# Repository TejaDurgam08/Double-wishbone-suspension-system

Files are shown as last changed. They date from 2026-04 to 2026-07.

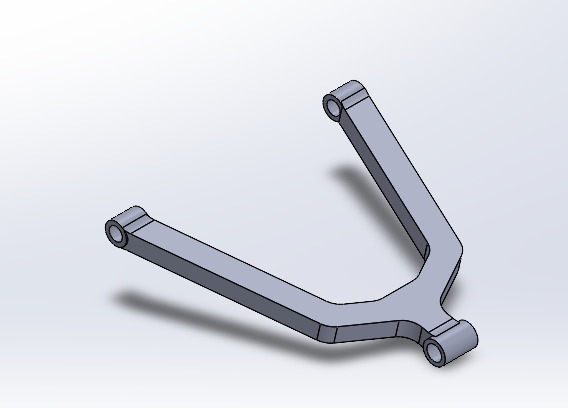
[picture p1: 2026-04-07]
images/IMG-20251128-WA0012.jpg

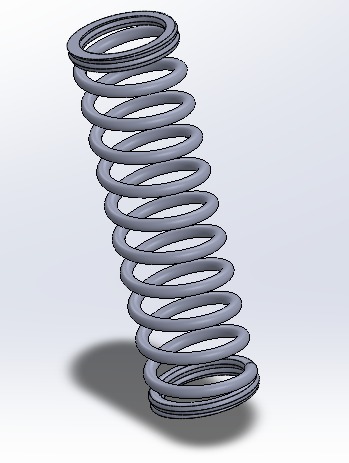
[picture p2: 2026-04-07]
images/IMG-20251128-WA0010.jpg

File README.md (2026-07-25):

# Double-wishbone-suspension-system

IMG-20251128-WA0008
IMG-20251128-WA0011

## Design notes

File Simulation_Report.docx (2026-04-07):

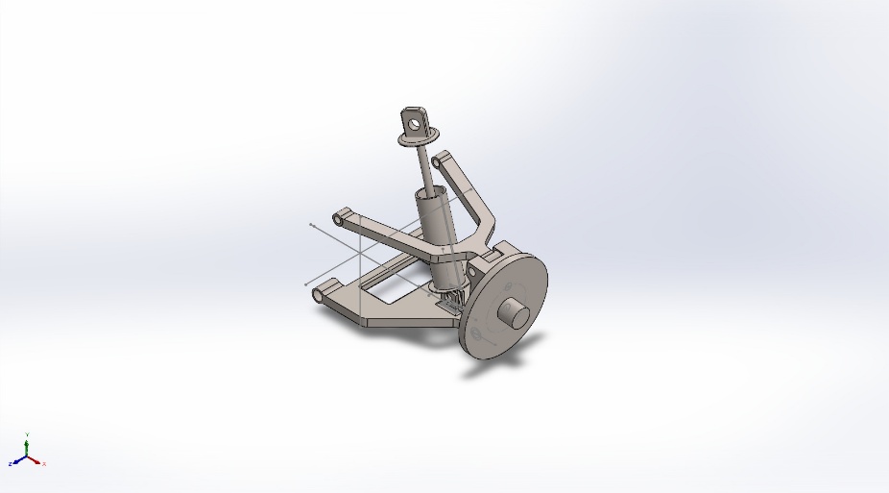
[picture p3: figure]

Simulation of tests_2 - Copy

Date: 28 November 2025
Designer: Solidworks

Study name: Test_1_static

Analysis type: Static
Description No Data

# Assumptions

# Model Information

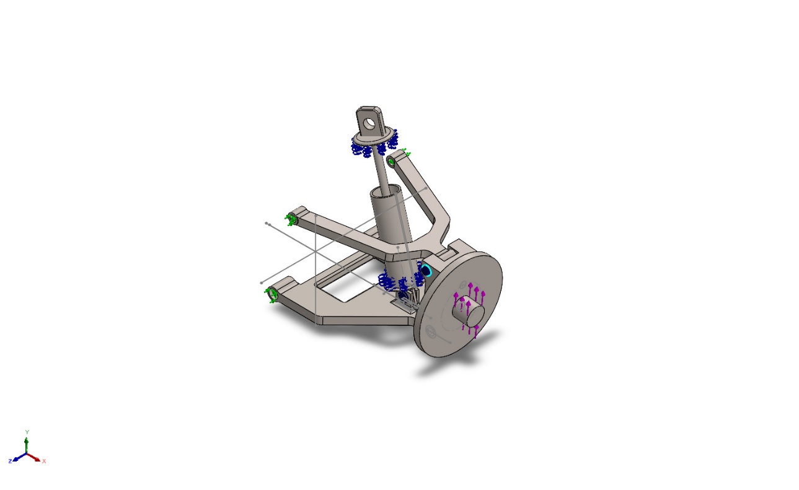
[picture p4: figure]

Model name: tests_2 - Copy

Current Configuration: Default

Solid Bodies
Document Name and Reference | Treated As | Volumetric Properties | Document Path/Date Modified
Boss-Extrude7[1] | Solid Body | Mass:0.00462 kg Volume:6e-07 m^3 Density:7,700 kg/m^3 Weight:0.045276 N | D:\Dome_assignment\DoME project\my\version_1\base_2.SLDPRT Nov 17 12:33:01 2025

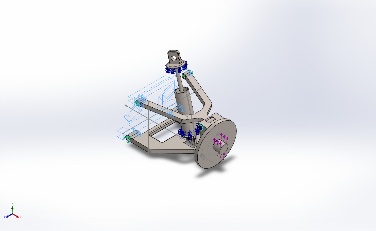
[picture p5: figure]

Cut-Extrude2 | Solid Body | Mass:0.741422 kg Volume:9.62885e-05 m^3 Density:7,700 kg/m^3 Weight:7.26593 N | D:\Dome_assignment\DoME project\my\version_1\base_2.SLDPRT Nov 17 12:33:01 2025

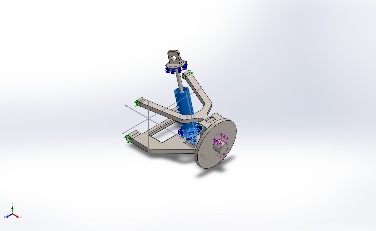
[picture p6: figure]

Revolve2 | Solid Body | Mass:0.161137 kg Volume:2.09269e-05 m^3 Density:7,700 kg/m^3 Weight:1.57914 N | D:\Dome_assignment\DoME project\my\version_1\damper_pipe.SLDPRT Nov 27 22:18:26 2025

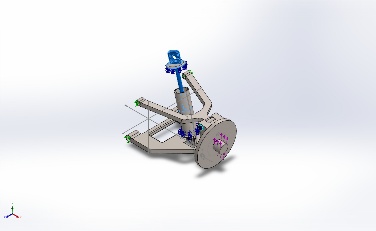
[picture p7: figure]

Cut-Extrude1 | Solid Body | Mass:0.0996239 kg Volume:1.29382e-05 m^3 Density:7,700 kg/m^3 Weight:0.976314 N | D:\Dome_assignment\DoME project\my\version_1\damper_rod.SLDPRT Nov 28 00:48:46 2025

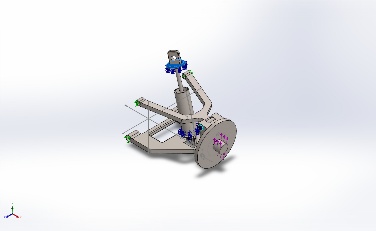
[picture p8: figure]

Fillet1 | Solid Body | Mass:0.0174824 kg Volume:2.27044e-06 m^3 Density:7,700 kg/m^3 Weight:0.171327 N | D:\Dome_assignment\DoME project\my\version_1\damper_rod.SLDPRT Nov 28 00:48:46 2025

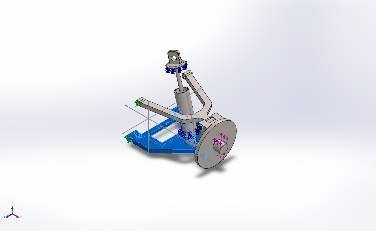
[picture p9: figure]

Fillet16 | Solid Body | Mass:0.854805 kg Volume:0.000111014 m^3 Density:7,700 kg/m^3 Weight:8.37709 N | D:\Dome_assignment\DoME project\my\version_1\lower_2 - Copy.SLDPRT Nov 17 13:17:45 2025

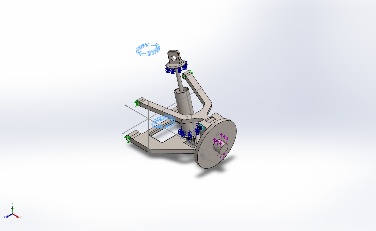
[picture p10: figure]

Cut-Extrude1 | Solid Body | Mass:0.312714 kg Volume:4.06231e-05 m^3 Density:7,697.92 kg/m^3 Weight:3.06459 N | D:\Dome_assignment\DoME project\my\version_1\spring - Copy (2).SLDPRT Nov 28 02:52:23 2025

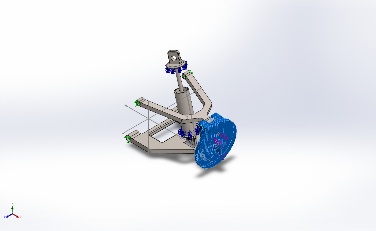
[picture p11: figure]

Boss-Extrude4 | Solid Body | Mass:1.26652 kg Volume:0.000164483 m^3 Density:7,700 kg/m^3 Weight:12.4119 N | D:\Dome_assignment\DoME project\my\version_1\tyre hub - Copy.SLDPRT Nov 27 22:33:03 2025
Fillet4 | Solid Body | Mass:0.331277 kg Volume:4.30229e-05 m^3 Density:7,700 kg/m^3 Weight:3.24651 N | D:\Dome_assignment\DoME project\my\version_1\upper_2 - Copy.SLDPRT Nov 27 21:55:36 2025

# Study Properties

Study name | Test_1_static
Analysis type | Static
Mesh type | Solid Mesh
Thermal Effect: | On
Thermal option | Include temperature loads
Zero strain temperature | 298 Kelvin
Include fluid pressure effects from SOLIDWORKS Flow Simulation | Off
Solver type | Automatic
Inplane Effect: | Off
Soft Spring: | Off
Inertial Relief: | Off
Incompatible bonding options | Automatic
Large displacement | Off
Compute free body forces | On
Friction | Off
Use Adaptive Method: | Off
Result folder | SOLIDWORKS document (D:\Dome_assignment\DoME project\my\version_1)

# Units

Unit system: | SI (MKS)
Length/Displacement | mm
Temperature | Kelvin
Angular velocity | Rad/sec
Pressure/Stress | N/m^2

# Material Properties

Model Reference | Properties | Components

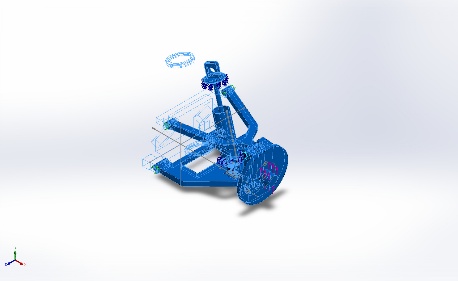
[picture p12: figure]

| Name: Alloy Steel Model type: Linear Elastic Isotropic Default failure criterion: Max von Mises Stress Yield strength: 6.20422e+08 N/m^2 Tensile strength: 7.23826e+08 N/m^2 Elastic modulus: 2.1e+11 N/m^2 Poisson's ratio: 0.28 Mass density: 7,700 kg/m^3 Shear modulus: 7.9e+10 N/m^2 Thermal expansion coefficient: 1.3e-05 /Kelvin | SolidBody 1(Boss-Extrude7[1])(base_2-2), SolidBody 2(Cut-Extrude2)(base_2-2), SolidBody 1(Revolve2)(damper_pipe-1), SolidBody 1(Cut-Extrude1)(damper_rod-1), SolidBody 2(Fillet1)(damper_rod-1), SolidBody 1(Fillet16)(lower_2 - Copy-1), SolidBody 1(Cut-Extrude1)(spring - Copy (2)-1), SolidBody 1(Boss-Extrude4)(tyre hub - Copy-1), SolidBody 1(Fillet4)(upper_2 - Copy-1)

Curve Data:N/A

# Loads and Fixtures

Fixture name | Fixture Image | Fixture Details

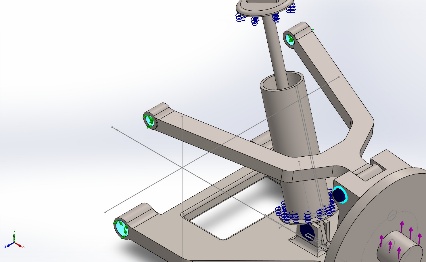
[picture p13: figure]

Fixed Hinge-1 | | Entities: 4 face(s) Type: Fixed Hinge

Resultant Forces

Components | X | Y | Z | Resultant
Reaction force(N) | -60.9249 | -596.9 | 1.20401e-05 | 600.001
Reaction Moment(N.m) | 0 | 0 | 0 | 0

Load name | Load Image | Load Details

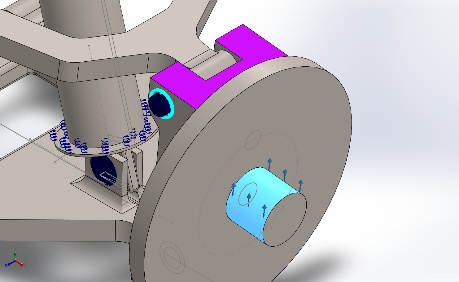
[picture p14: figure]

Force-1 | | Entities: 1 face(s) Reference: Face< 1 > Type: Apply force Values: ---, ---, -,600 N

# Connector Definitions

Connector Name | Connector Details | Connector Image

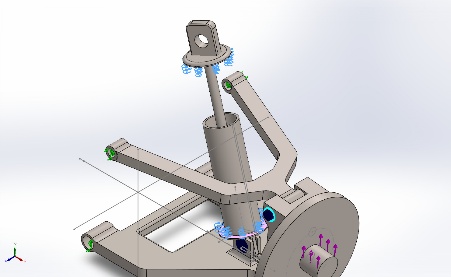
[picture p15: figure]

Spring Connector-1 | Entities: 2 face(s) Type: Spring(Flat parallel faces)(Compression & Extension) Normal stiffness value: 8,108.16 N/m Tangential Stiffness: 0 N/m | Spring Connector-1

Pin/Bolt/Bearing Connector

Model Reference | Connector Details | Strength Details

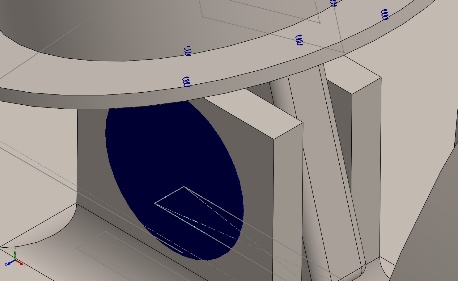
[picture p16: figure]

Pin Connector-1 | Entities: 3 face(s) Type: Pin With retaining ring (No translation): Yes With key (No rotation): No Connection Type: Rigid Units: SI Rotational stiffness value: 0 | No Data

Connector Forces Joint 1

Type | X-Component | Y-Component | Z-Component | Resultant
Axial Force (N) | 0 | 0 | 10.955 | -10.955
Shear Force (N) | 6.9449 | -6.2763 | 0 | 9.3607
Torque (N.m) | 0 | 0 | 1.7213e-11 | -1.7213e-11
Bending moment (N.m) | -0.0595 | -0.0048362 | 0 | 0.059696

Connector Forces Joint 2

Type | X-Component | Y-Component | Z-Component | Resultant
Axial Force (N) | 0 | 0 | 10.955 | -10.955
Shear Force (N) | 6.9449 | -6.2763 | 0 | 9.3607
Torque (N.m) | 0 | 0 | 1.7211e-11 | -1.7211e-11
Bending moment (N.m) | 0.085459 | 0.033561 | 0 | 0.091813

Connector Forces Joint 3

Type | X-Component | Y-Component | Z-Component | Resultant
Axial Force (N) | -0 | -0 | -10.798 | 10.798
Shear Force (N) | 1.4845 | -6.2238 | 0 | 6.3984
Torque (N.m) | 0 | 0 | 1.7213e-11 | -1.7213e-11
Bending moment (N.m) | 0.059799 | 0.017382 | 0 | 0.062274

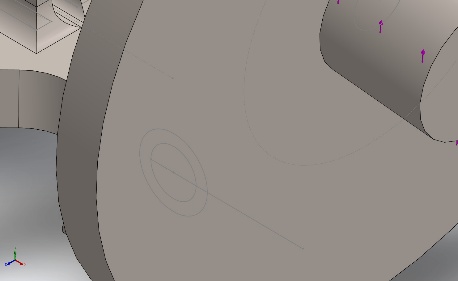
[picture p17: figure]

Pin Connector-4 | Entities: 3 face(s) Type: Pin With retaining ring (No translation): Yes With key (No rotation): No Connection Type: Rigid Units: SI Rotational stiffness value: 0 | No Data

Connector Forces Joint 1

Type | X-Component | Y-Component | Z-Component | Resultant
Axial Force (N) | 0 | 0 | -0.51797 | -0.51797
Shear Force (N) | 569.04 | 1,198.2 | 0 | 1,326.4
Torque (N.m) | 0 | 0 | -1.9454e-12 | -1.9454e-12
Bending moment (N.m) | 6.7217 | -1.5449 | 0 | 6.8969

Connector Forces Joint 2

Type | X-Component | Y-Component | Z-Component | Resultant
Axial Force (N) | 0 | 0 | -0.51797 | -0.51797
Shear Force (N) | 569.04 | 1,198.2 | 0 | 1,326.4
Torque (N.m) | 0 | 0 | -1.5469e-12 | -1.5469e-12
Bending moment (N.m) | 14.252 | -8.4158 | 0 | 16.551

Connector Forces Joint 3

Type | X-Component | Y-Component | Z-Component | Resultant
Axial Force (N) | -0 | -0 | 17.493 | 17.493
Shear Force (N) | 410.21 | 1,098.3 | 0 | 1,172.4
Torque (N.m) | 0 | 0 | -1.944e-12 | -1.944e-12
Bending moment (N.m) | -6.1258 | 0.40365 | 0 | 6.1391

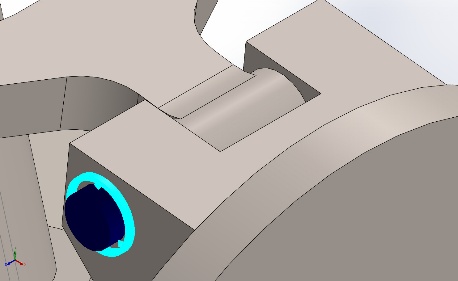
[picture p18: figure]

Pin Connector-5 | Entities: 3 face(s) Type: Pin With retaining ring (No translation): Yes With key (No rotation): No Connection Type: Rigid Units: SI Rotational stiffness value: 0 | No Data

Connector Forces Joint 1

Type | X-Component | Y-Component | Z-Component | Resultant
Axial Force (N) | -0 | -0 | 37.484 | 37.484
Shear Force (N) | -262.15 | 90.807 | 0 | 277.43
Torque (N.m) | 0 | 0 | -2.5977e-12 | -2.5977e-12
Bending moment (N.m) | -0.83893 | -0.29251 | 0 | 0.88846

Connector Forces Joint 2

Type | X-Component | Y-Component | Z-Component | Resultant
Axial Force (N) | -0 | -0 | 65.881 | 65.881
Shear Force (N) | 354.56 | 22.88 | 0 | 355.3
Torque (N.m) | 0 | 0 | -2.4312e-12 | -2.4312e-12
Bending moment (N.m) | -2.176 | -5.6127 | 0 | 6.0197

Connector Forces Joint 3

Type | X-Component | Y-Component | Z-Component | Resultant
Axial Force (N) | 0 | 0 | -65.881 | -65.881
Shear Force (N) | -354.56 | -22.88 | 0 | 355.3
Torque (N.m) | 0 | 0 | -2.5868e-12 | -2.5868e-12
Bending moment (N.m) | 2.5751 | -0.57265 | 0 | 2.638

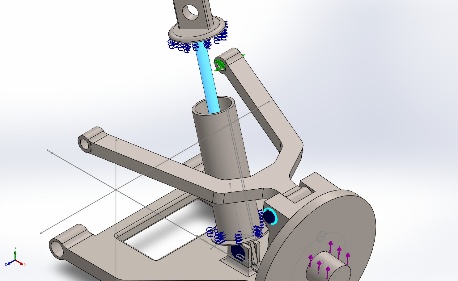
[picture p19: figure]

Pin Connector-6 | Entities: 2 face(s) Type: Pin With retaining ring (No translation): Yes With key (No rotation): No Connection Type: Distributed Units: SI Rotational stiffness value: 0 | No Data

Connector Forces Joint 1

Type | X-Component | Y-Component | Z-Component | Resultant
Axial Force (N) | 0.0016637 | -0.0059329 | -0 | 0.0061618
Shear Force (N) | 0.00068609 | 0.00019239 | -6.5077e-05 | 0.00071552
Torque (N.m) | 2.6322e-14 | -9.3867e-14 | -0 | 9.7488e-14
Bending moment (N.m) | -4.2029e-06 | -1.1786e-06 | -5.4881e-05 | 5.5055e-05

Connector Forces Joint 2

Type | X-Component | Y-Component | Z-Component | Resultant
Axial Force (N) | -0.0016637 | 0.0059329 | 0 | -0.0061618
Shear Force (N) | -0.00068609 | -0.00019239 | 6.5077e-05 | 0.00071552
Torque (N.m) | -2.1816e-13 | 7.7799e-13 | 0 | -8.08e-13
Bending moment (N.m) | -2.4233e-06 | -6.7954e-07 | -2.0471e-05 | 2.0625e-05

# Interaction Information

Interaction | Interaction Image | Interaction Properties
Global Interaction | | Type: Bonded Components: 1 component(s) Options: Independent mesh

# Mesh information

Mesh type | Solid Mesh
Mesher Used: | Blended curvature-based mesh
Jacobian points for High quality mesh | 16 Points
Maximum element size | 10.215 mm
Minimum element size | 0.51075 mm
Mesh Quality | High
Remesh failed parts independently | Off
Reuse mesh for identical parts in an assembly (Blended curvature-based mesher only) | Off

## Mesh information - Details

Total Nodes | 265399
Total Elements | 159451
Maximum Aspect Ratio | 50.794
% of elements with Aspect Ratio < 3 | 95.5
Percentage of elements with Aspect Ratio > 10 | 0.074
Percentage of distorted elements | 0
Time to complete mesh(hh;mm;ss): | 00:00:38
Computer name: | TEJADURGAM

## Mesh Control Information:

Mesh Control Name | Mesh Control Image | Mesh Control Details

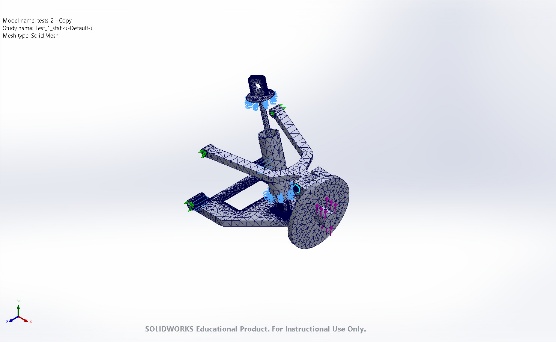
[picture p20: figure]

Control-1 | | Entities: 4 face(s) Units: mm Size: 0.5 Ratio: 0.5
Control-2 | | Entities: 8 face(s) Units: mm Size: 1 Ratio: 1

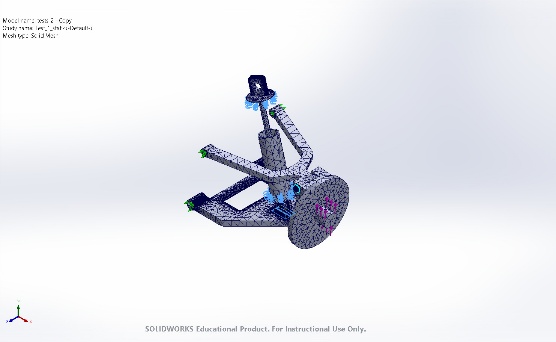
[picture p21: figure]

Control-3 | | Entities: 8 face(s) Units: mm Size: 0.5 Ratio: 0.5

## Mesh Quality Plots

Name | Type | Min | Max
Quality1 | Mesh | - | -

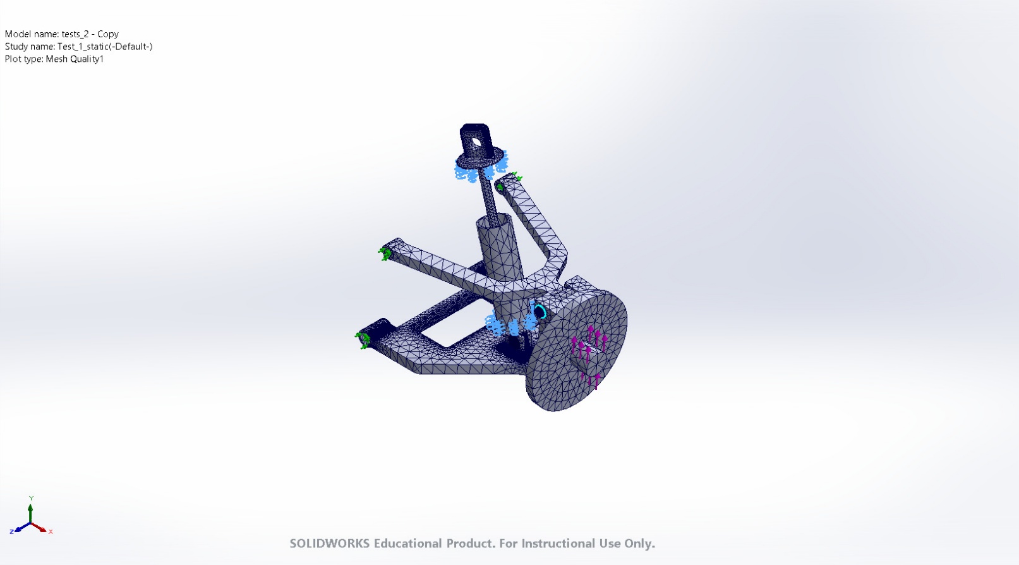
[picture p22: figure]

tests_2 - Copy-Test_1_static-Quality-Quality1

# Sensor Details

No Data

# Resultant Forces

## Reaction forces

Selection set | Units | Sum X | Sum Y | Sum Z | Resultant
Entire Model | N | -60.9249 | -596.9 | 1.20401e-05 | 600.001

## Reaction Moments

Selection set | Units | Sum X | Sum Y | Sum Z | Resultant
Entire Model | N.m | 0 | 0 | 0 | 0

## Free body forces

Selection set | Units | Sum X | Sum Y | Sum Z | Resultant
Entire Model | N | 0.00122065 | 0.00772102 | -0.00320676 | 0.0084491

## Free body moments

Selection set | Units | Sum X | Sum Y | Sum Z | Resultant
Entire Model | N.m | 0 | 0 | 0 | 1e-33

# Beams

No Data

# Study Results

Name | Type | Min | Max
Stress1 | VON: von Mises Stress | 4.769e-01N/m^2 Node: 59681 | 4.849e+08N/m^2 Node: 183649

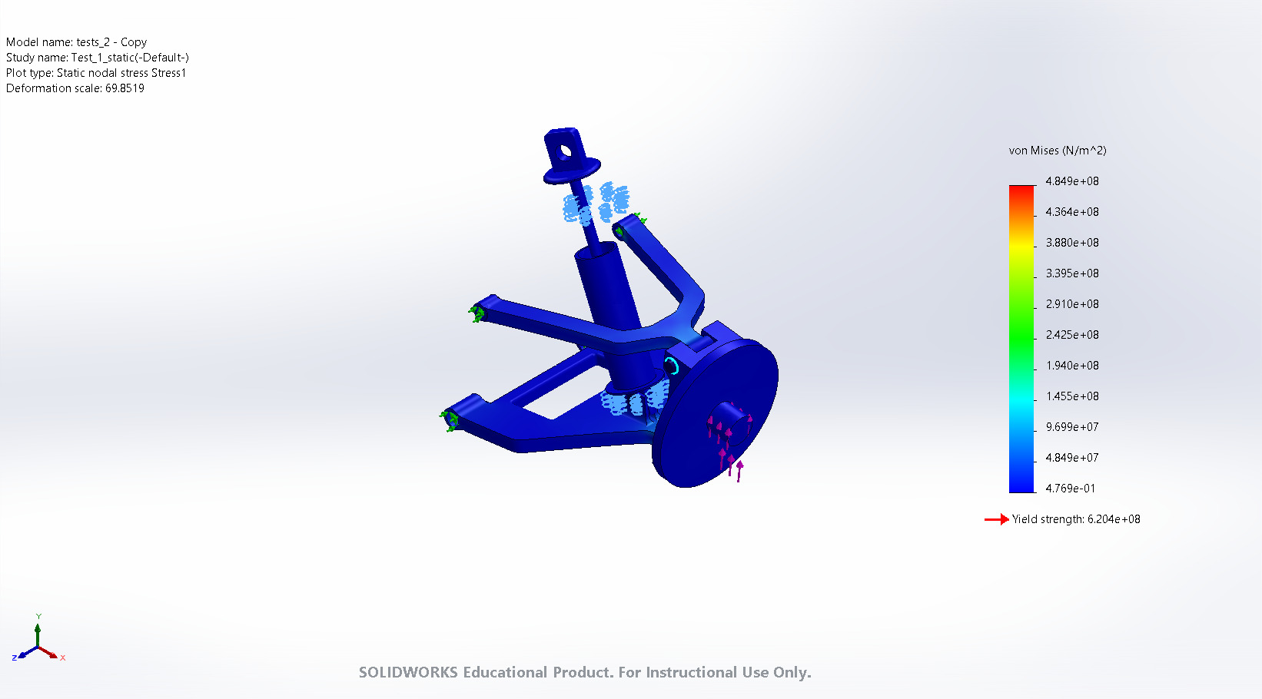
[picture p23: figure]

tests_2 - Copy-Test_1_static-Stress-Stress1

Name | Type | Min | Max
Displacement1 | URES: Resultant Displacement | 4.133e-04mm Node: 663 | 3.852e-01mm Node: 60662

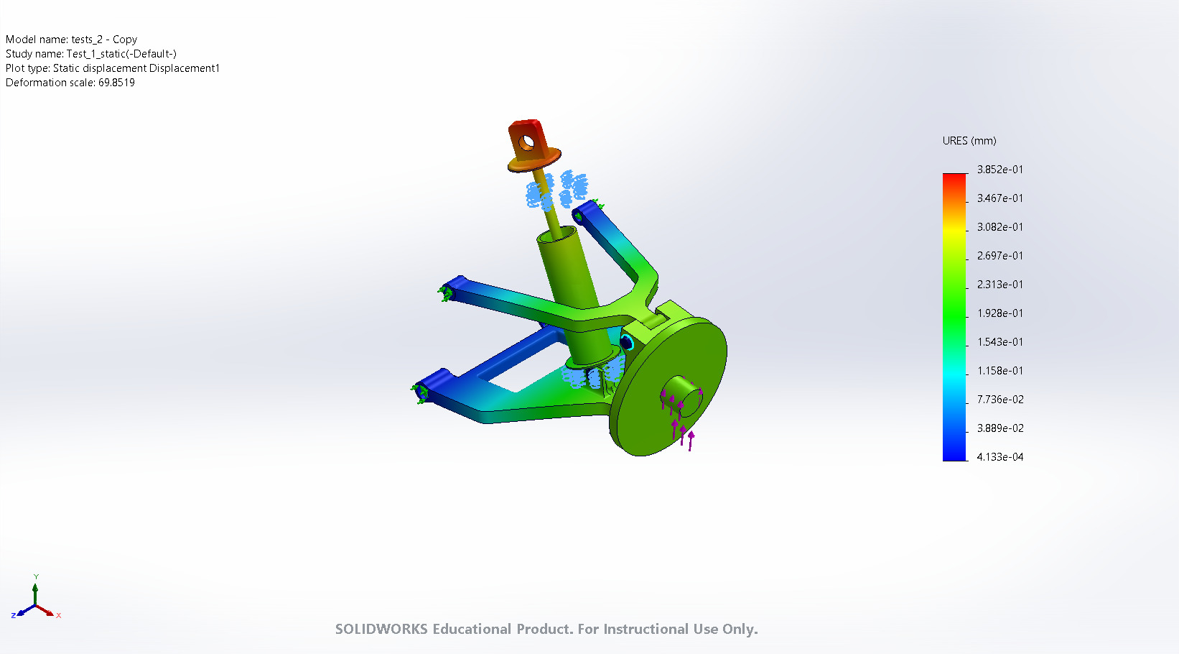
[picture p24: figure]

tests_2 - Copy-Test_1_static-Displacement-Displacement1

Name | Type | Min | Max
Strain1 | ESTRN: Equivalent Strain | 1.762e-12 Element: 146391 | 9.967e-04 Element: 81942

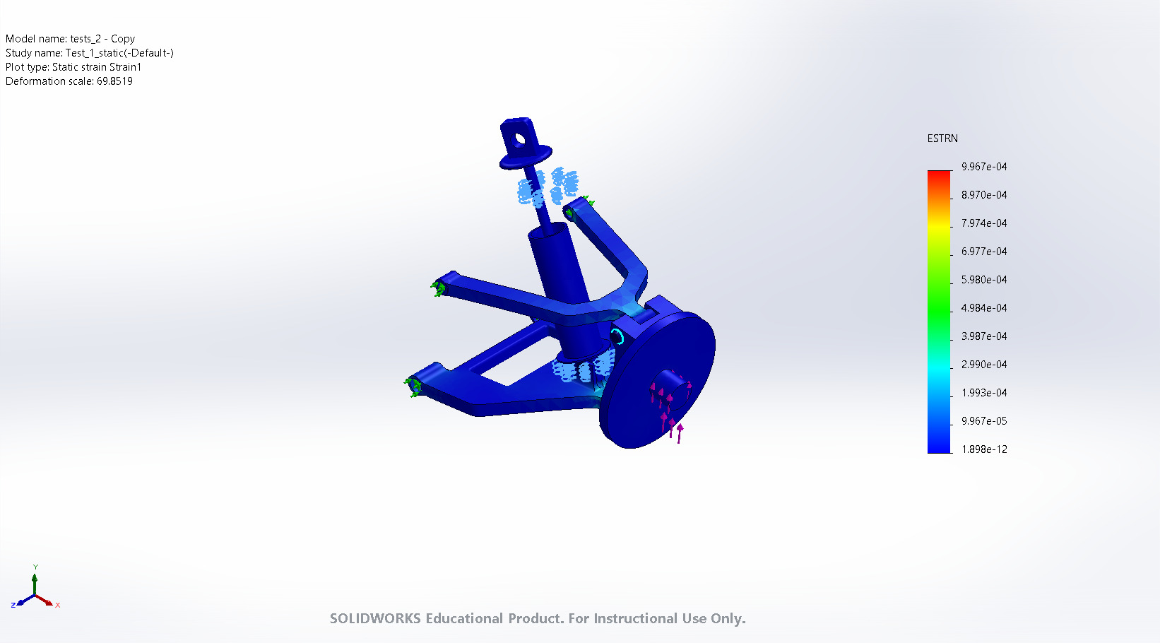
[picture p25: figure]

tests_2 - Copy-Test_1_static-Strain-Strain1

Name | Type | Min | Max
Factor of Safety1 | Automatic | 1.279e+00 Node: 183649 | 1.301e+09 Node: 59681

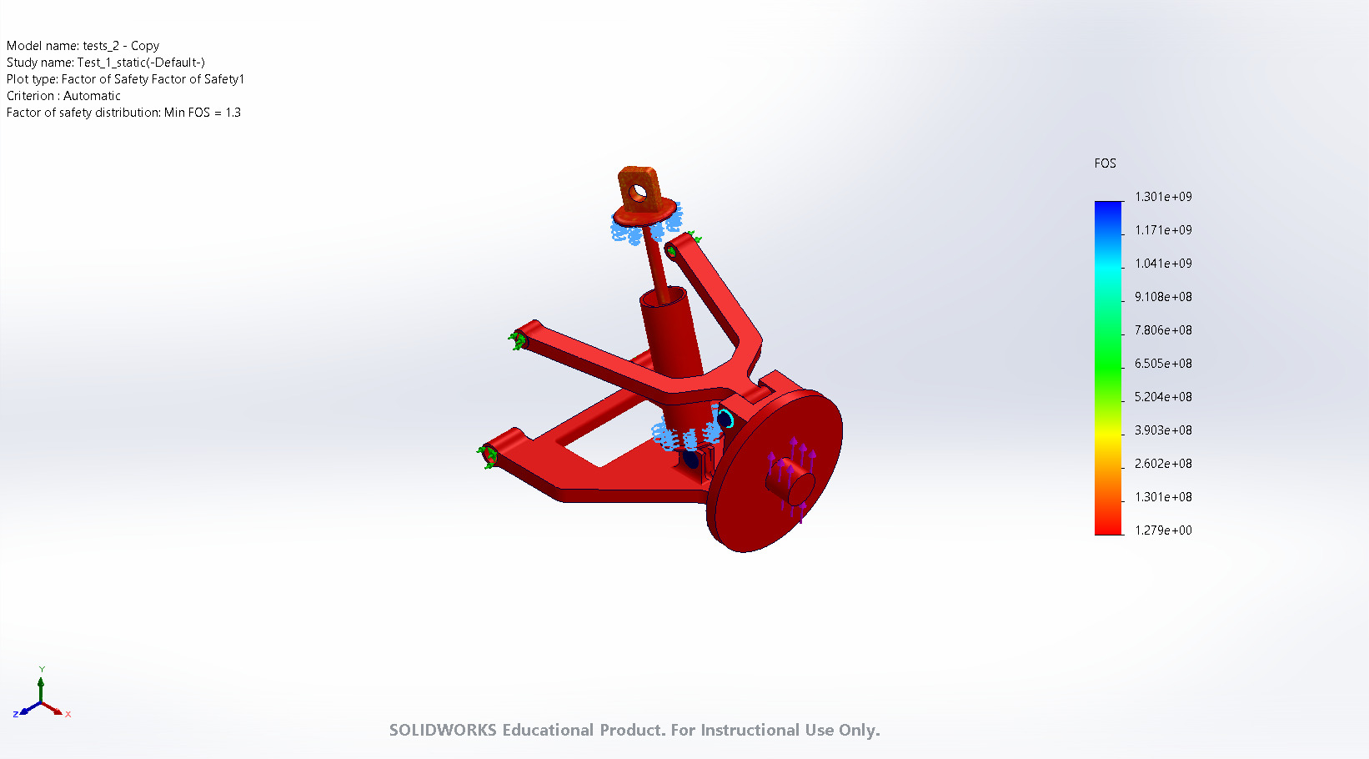
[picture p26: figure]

tests_2 - Copy-Test_1_static-Factor of Safety-Factor of Safety1

# Conclusion

Analyzed with SOLIDWORKS Simulation Simulation of tests_2 - Copy 16

Analyzed with SOLIDWORKS Simulation Simulation of tests_2 - Copy 1

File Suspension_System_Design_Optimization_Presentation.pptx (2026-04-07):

## Design and Optimization of a Four-Wheeler Suspension System

TEAM MEMBERS
- D.TEJA-ME23BT049
- M.PREM SAI -ME23BT037
- N.MAHESH- ME23BT035

## OBJECTIVE

- Analyze and design a four-wheeler suspension consider static and dynamic loads. Perform fatigue and stress analysis using DME data. Propose an optimized design balancing strength and ride comfort.

## Project Overview &Problem Statement

- This project focuses on analyzing and designing a helical coil spring suspension considering real loading conditions.
- Both static (vehicle weight) and dynamic (road-induced shocks) loads are evaluated.
- In this project, a helical coil spring integrated within a double-wishbone system is analyzed and designed.
- Suspension performance must be enhanced without compromising comfort, safety, or manufacturability.
- The project evaluates performance parameters such as stiffness, damping, stress, and fatigue life to improve overall suspension efficiency.

Double_Wishbone_Suspension

## Project Overview &Problem Statement

- The study focuses on a double wishbone suspension system integrated with a helical coil spring and damper, commonly used in passenger vehicles for stability and ride comfort.
- Select materials for spring, damper, and wishbone arms that can safely carry vehicle loads while minimizing weight and cost.
- Develop a CAD model and assembly that captures real-world constraints: suspension travel, clearances, and manufacturability.
- Analyze and optimize the spring–damper–wishbone system to ensure structural integrity, ride comfort, and handling performance.

## DESIGN CONSIDERATIONS

1. Structural Integrity
- Use high-strength, fatigue-resistant materials for spring, damper, and wishbone.
- Design joints and contacts to avoid stress concentrations.
- Ensure adequate safety factors for static and fatigue loads
2. Ride Comfort:
- Tune spring stiffness to absorb bumps.
- Set damper coefficient to control oscillations without harshness.
3. Minimum Ride Height
- Ensure the suspension allows proper ground clearance and ergonomically safe vehicle entry/exit without bottoming out.

## DESIGN CONSIDERATIONS

4. Damper Ergonomics
- Damper and spring response should provide smooth motion with minimal driver input force for comfort and control.
5. Wishbone Geometry
- Dimensions of wishbone arms to achieve correct wheel travel and kinematics while keeping the system compact.
6. Link Geometry & Joint Placement
- Proper geometry and pivot placement ensure smooth motion, uniform load distribution, and stable suspension operation.
7. Base & Wheel Stability
- Suspension geometry and spring–damper tuning should maintain vehicle stability, center of gravity, and handling performance during turns, bumps, and braking.

## MODELING AND ASSEMBLY

- Here are the CAD-modeled components that form the complete four-wheeler suspension assembly, including the helical coil spring, hydraulic damper, and double-wishbone arms.
- These visuals help in understanding the geometry, mounting points, kinematics, and overall interaction between the spring–damper unit and the wishbone linkage.
- They also illustrate how the spring and damper compress and extend during wheel movement,the upper and lower wishbones control wheel alignment and motion path

main

## MODELING AND ASSEMBLY

Damper (Mono-Tube):
Material Selection:
- High-strength steel or aluminum alloys
- Polymer or rubber sealing materials
Function:
- Controls spring oscillations
- Improves ride stability and handling
- Reduces Vibrations & Impacts


## MODELING AND ASSEMBLY

Helical Spring:
Material Selection:
- Chrome–Silicon (Cr–Si) Steel
High strength, excellent fatigue resistance, ideal for heavy-load and high-stress suspension springs.
- Chrome–Vanadium (Cr–V) Steel
Good toughness, high endurance limit, better performance under repeated dynamic loads.
- Spring Steel (High-Carbon Steel)
Cost-effective, reliable option with good elasticity and durability for standard suspension systems.
Function:
- Supports Vehicle Weight
- Absorbs Road Shocks
- Maintains Suspension Geometry

spring

## MODELING AND ASSEMBLY

Double Wishbone :
Material selection:
- High-strength steel (mild steel or alloy steel)
- Aluminum alloy (e.g., 6061-T6 or 7075-T6)
- Forged steel (for high-performance)
Upper Wishbone (A-Arm):
Function:
- Controls upper wheel movement
- Provides mounting for damper/spring
- Improves vehicle handling
Lower Wishbone (A-Arm):
Function:
- Guides vertical wheel travel
- Carries main suspension load
- Ensures stable support and alignment of the shock absorber.

bone 1
bone 2

## MODELING AND ASSEMBLY

HUB:
Material Selection:
- High-strength steel (mild steel or alloy steel)
- Aluminum alloy (e.g., 6061-T6 or 7075-T6)
- Forged steel (for high-performance)
Function:
- Supports and connects suspension components
- Maintains wheel alignment and load distribution
- Provides a rigid base for rotation and braking loads

tyre

## CALCULATIONS

-FOR SPRING

calculation 1

## CALCULATIONS

calculation 2

## CALCULATIONS

cal3

## CALCULATIONS

cal 4

## CALCULATIONS

cal5

according to tresca theory

## CALCULATIONS

cal 6

## CALCULATIONS

cal 7

## CALCULATIONS

cal 8

## CALCULATIONS

-FOR FATIGUE

fatigue cal

## CALCULATIONS

fatigue cal 2

## CALCULATIONS

fatigue cal 3

## CALCULATIONS

CAL 3

## FEA

fea1

## FEA

fea2

## FEA

meshing

## CONCLUSION

- The suspension system was successfully designed and optimized using a helical spring, damper, and double-wishbone geometry. Material selection and FEA ensured safe stress limits, proper stiffness, and improved vibration control. The final design achieves a balanced combination of ride comfort, stability, and structural strength, making it suitable for real-world vehicle conditions.

## References

• Shigley’s Mechanical Engineering Design
• Automotive Suspension Manuals-
https://www.toyotabharat.com/documents/brochures/fortuner-mmc/combined-specsheet.pdf
• Research papers
https://www.ijcrt.org/papers/IJCRT2502631.pdf
- youtube-
1)https://youtu.be/S_GraRRbxLg?si=6J07aS1lmIBHZagr
2)https://youtu.be/3CmynYyGpnY?si=Gk4DMdzRS7vpd2nl

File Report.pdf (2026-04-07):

# Design and Optimization of a Four-Wheeler

# Suspension System

### Team Members:

### D. Teja (ME23BT049)

### M. Prem Sai (ME23BT037)

### N. Mahesh (ME23BT035)

### November 28, 2025

## Contents

1 Introduction | 4
2 Design Methodology and Considerations | 5
3 Modeling and Component Assembly | 6
4 Calculations and Analytical Design | 9
5 Fatigue and Finite Element Analysis (FEA) | 11
6 Conclusion | 12

7 References | 12

## 1 Introduction

### 1.1 Project Overview

This report details the analysis and design of a four-wheeler suspension system, specifically focusing on a double-wishbone configuration integrated with a helical coil spring. The suspension system is a critical component of any vehicle, acting as the interface between the road and the chassis.

The primary objective of this project is to analyze and design a suspension system that can withstand both static loads (the weight of the vehicle itself) and dynamic loads (shocks induced by uneven road surfaces). By performing fatigue and stress analysis using Design of Machine Elements (DME) data, the team aims to propose an optimized design

that effectively balances structural strength with ride comfort.

As seen in Figure ??, the system utilizes a double-wishbone architecture. This setup is widely favored in passenger vehicles because it allows for superior control over wheel movement and alignment compared to simpler systems.

### 1.2 Problem Statement

Analyze and design a four-wheeler suspension consider static and dynamic loads. Perform fatigue and stress analysis using DME data. Propose an optimized design balancing strength and ride comfort.

The core challenge lies in enhancing the performance of the suspension without compromising safety, comfort, or the ability to manufacture the parts cost-effectively. To achieve this, the project evaluates several key performance parameters:

- Stiffness: How resistant the spring is to compression.
- Damping: How quickly the system stops bouncing after a bump.
- Fatigue Life: How many cycles of compression the system can endure before failing.

## 2 Design Methodology and Considerations

When designing a suspension system, engineers must balance conflicting requirements. For example, a very stiff spring handles heavy loads well but makes the ride uncomfortable for passengers. The following considerations guided this design:

### 2.1 Structural Integrity

The safety of the vehicle depends on the suspension’s ability to resist failure. The design employs high-strength, fatigue-resistant materials for critical components like the spring, damper, and wishbones. Furthermore, joints and contact points are designed specifically to avoid stress concentrations—areas where force gathers and creates weak points. Adequate safety factors are applied to ensure the system can handle loads significantly higher than expected during normal operation.

### 2.2 Ride Comfort and Ergonomics

Ride comfort is determined by how the system manages energy. The spring stiffness is tuned to absorb bumps, while the damper coefficient is set to control oscillations. Classroom Example: Think of the spring as a mattress that cushions you, and the damper as a door closer that prevents the mattress from bouncing up and down endlessly. Additionally, the design ensures a minimum ride height to prevent the vehicle from ”bottoming out” (hitting the ground) on rough terrain, while also allowing for ergonomically safe

entry and exit for passengers.

### 2.3 Geometry and Stability

The geometry of the wishbone arms is calculated to achieve specific wheel travel paths. Proper pivot placement ensures smooth motion and uniform load distribution. This geometry is crucial for maintaining the vehicle’s center of gravity and handling performance during turns, braking, and acceleration.

## 3 Modeling and Component Assembly

A complete Computer-Aided Design (CAD) model was developed to visualize the inter-

action between components.


Figure 1: Full CAD Assembly of the Double-Wishbone Suspension.

The assembly helps in understanding the kinematics—how the parts move in relation to one another. It illustrates how the spring and damper compress and extend while the upper and lower wishbones control the wheel’s alignment.

### 3.1 The Damper (Mono-Tube)

The damper acts as the energy dissipater. It is modeled as a mono-tube design using high-strength steel or aluminum alloys. Its primary function is to dampen the oscillations of the spring, improving ride stability and reducing vibrations felt by the driver.


Figure 2: CAD Model of the Mono-Tube Damper.

### 3.2 The Helical Spring

The spring is the primary load-bearing component. Several materials were evaluated:

- Chrome-Silicon (Cr-Si) Steel: Chosen for its high strength and excellent fatigue

resistance, making it ideal for high-stress applications.

- Chrome-Vanadium (Cr-V) Steel: Offers good toughness and endurance limits.
- Spring Steel (High-Carbon): A cost-effective option for standard systems.

The spring supports the vehicle weight and absorbs road shocks.


Figure 3: CAD Model of the Helical Spring.

### 3.3 Double Wishbones (A-Arms)

The suspension utilizes two ”A” shaped arms.

- Upper Wishbone: Controls the upper movement of the wheel and provides a

mounting point for the damper/spring assembly.

- Lower Wishbone: Guides vertical wheel travel and carries the main suspension

load.

These are typically manufactured from forged steel or aluminum alloys (e.g., 6061-T6) to

ensure rigidity.


Figure 4: Lower Wishbone (Left) and Upper Wishbone (Right).

## 4 Calculations and Analytical Design

To ensure the design is valid, mathematical calculations were performed based on a reference vehicle: the Toyota Fortuner.

### 4.1 Vehicle Data

- Gross Vehicle Weight (Wgross): 2510 kg.
- Weight on one wheel (w): Assuming equal distribution, w = 2510/4 = 627.5 kg.
- Sprung Mass (ms): This is the mass actually supported by the spring (excluding

tires/brakes).

ms =

w
g

=

627.5
9.81
≈ 64.03 kg | (1)

### 4.2 Stiffness Calculations

The design targets a ride frequency of 1 Hz, which is standard for passenger cars to avoid motion sickness.

Wheel Rate (Kw): The stiffness of the suspension at the wheel.

Kw = 4π

2
f

2
nms = 4π

2

(1)²
(64.03) ≈ 2527.80 N/m | (2)

Spring Rate (Ks): Because the spring is mounted at an angle and on a lever arm (the wishbone), the spring must be stiffer than the wheel rate. Using a Motion Ratio (T R) of 0.6 and an inclination angle (θ) of 30◦
:

Ks =

Kw
T R² × cos(θ)

=

2527.80
0.6

2 × 0.866

≈ 8108.16 N/m | (3)

### 4.3 Shear Stress Analysis

Using Chrome-Silicon Steel (Sut = 2000 MPa), the maximum allowable shear stress (τmax)

is determined via the Tresca Failure Criterion.

The calculation is as follows:

τmax = 0.5 × Sut = 1000 MPa | (4)

### 4.4 Geometric Dimensioning

The geometric parameters were calculated using Wahl’s Stress Correction Factor (K), assuming a Spring Index (C) of 8.

Wahl’s Factor (K):

K =

4C − 1
4C − 4

+

0.615
C
= 1.184 | (5)

Axial Spring Force (Fs): The force at static equilibrium is calculated considering

the motion ratio and installation angle:

Fs =

w · g
T R cos(θ)
≈ 1207.6 N | (6)

Wire Diameter (d) and Mean Coil Diameter (D): Rearranging the shear stress

equation yields the ratio for geometric dimensioning:

D
d

3

=

τmaxπ
K · 8 · Fs

≈ 0.27 mm⁻²
(7)

Solving for d (with C = 8):

d =

r
8
0.27
≈ 5.44 mm | (8)

Consequently, the mean coil diameter is:

D = C × d ≈ 43.52 mm | (9)

Active Coils (N) and Solid Length (Ls): The number of active coils required to achieve the target stiffness (Ks) is:

N =

Gd⁴
8D³Ks
≈ 13.03 coils | (10)

The solid length (Ls) is determined to be 81.76 mm.

## 5 Fatigue and Finite Element Analysis (FEA)

### 5.1 Fatigue Analysis

Suspensions undergo constant cycling. To ensure the spring won’t snap over time, a fatigue analysis was performed using the Modified Goodman Criterion.

- Maximum Force (Fmax): 1267.6 N.
- Minimum Force (Fmin): 962.27 N.

From these, the Mean Force (Fm = 1084.9 N) and Alternating Force (Fa = 122.7 N) were

found. Converting these forces into shear stresses provided the inputs for the Goodman equation:
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
(11)

Solving this yielded a Factor of Safety (n) of 1.44, indicating a safe design.

### 5.2 Finite Element Analysis Results

The design was validated using SolidWorks simulation tools.


Figure 5: Von Mises Stress Distribution on the Suspension Assembly.

The Von Mises stress plot (Figure 5) highlights areas of maximum stress. The simu-

lation showed that the maximum stresses induced were within the yield strength limits of the material.


Figure 6: Factor of Safety Distribution Plot.

The FEA results confirmed a minimum Factor of Safety of 1.3 for the assembly. This aligns closely with the theoretical calculation of 1.44, validating the mathematical model.

## 6 Conclusion

The suspension system was successfully designed and optimized using a helical spring, damper, and double-wishbone geometry. The analytical calculations for spring stiffness and geometry were validated through both theoretical fatigue analysis and computational FEA simulations.

The final design achieves a balanced combination of ride comfort, stability, and structural strength. The calculated safety factors indicate that the system is suitable for real-world vehicle conditions, specifically for a vehicle in the class of a Toyota Fortuner.

## 7 References

1. Shigley’s Mechanical Engineering Design.
2. Automotive Suspension Manuals.

3. Toyota Fortuner Combined Spec Sheet: https://www.toyotabharat.com/documents/

brochures/fortuner-mmc/combined-specsheet.pdf. (https://www.toyotabharat.com/documents/brochures/fortuner-mmc/combined-specsheet.pdf)

4. Research Paper: https://www.ijcrt.org/papers/IJCRT2502631.pdf.
5. YouTube Resource 1: https://youtu.be/S_GraRRbxLg?si=6J07aS1lmIBHZagr.
6. YouTube Resource 2: https://youtu.be/3CmynYyGpnY?si=Gk4DMdzRS7vpd2nl.

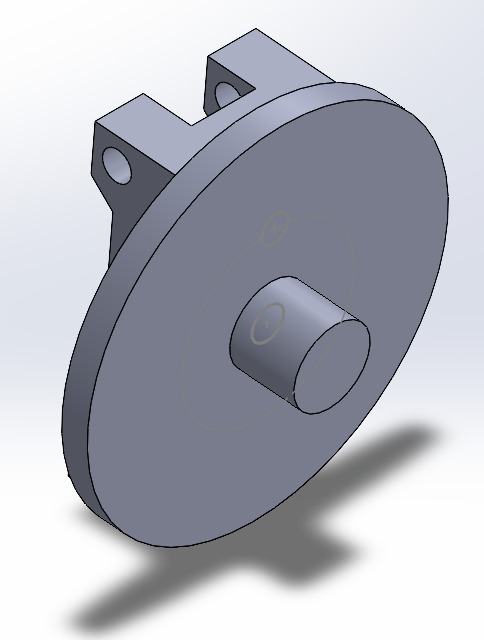
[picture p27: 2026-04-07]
images/IMG-20251128-WA0015.jpg

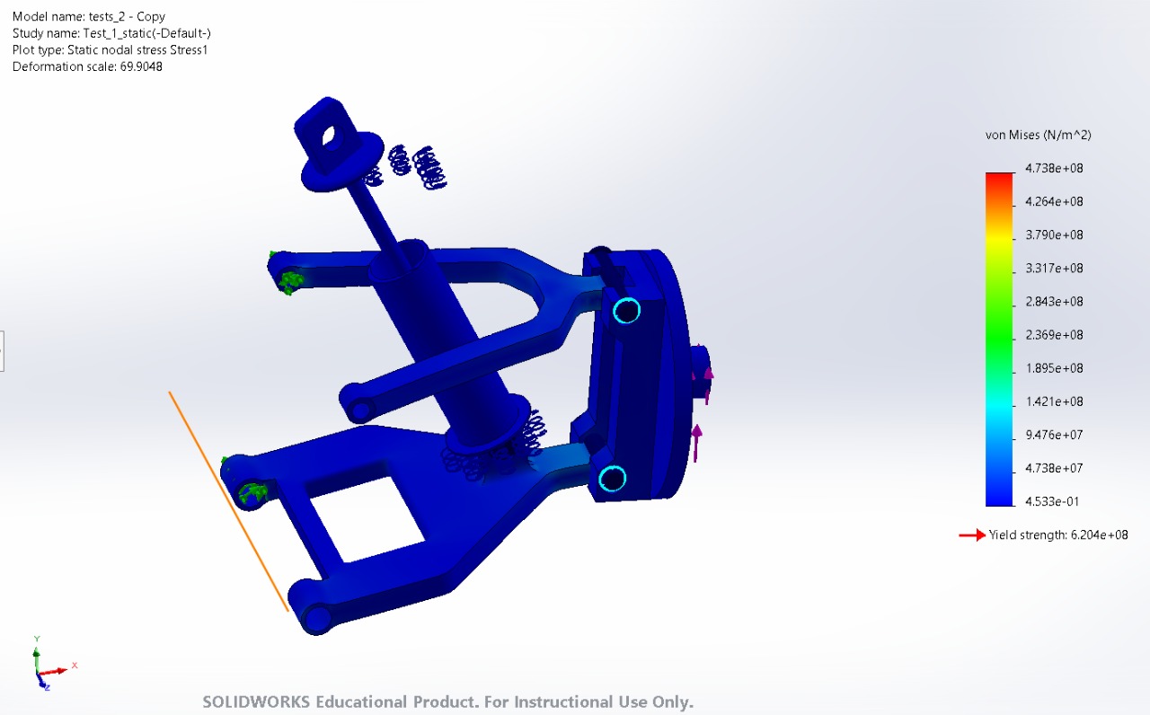
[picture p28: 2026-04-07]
images/IMG-20251128-WA0011.jpg

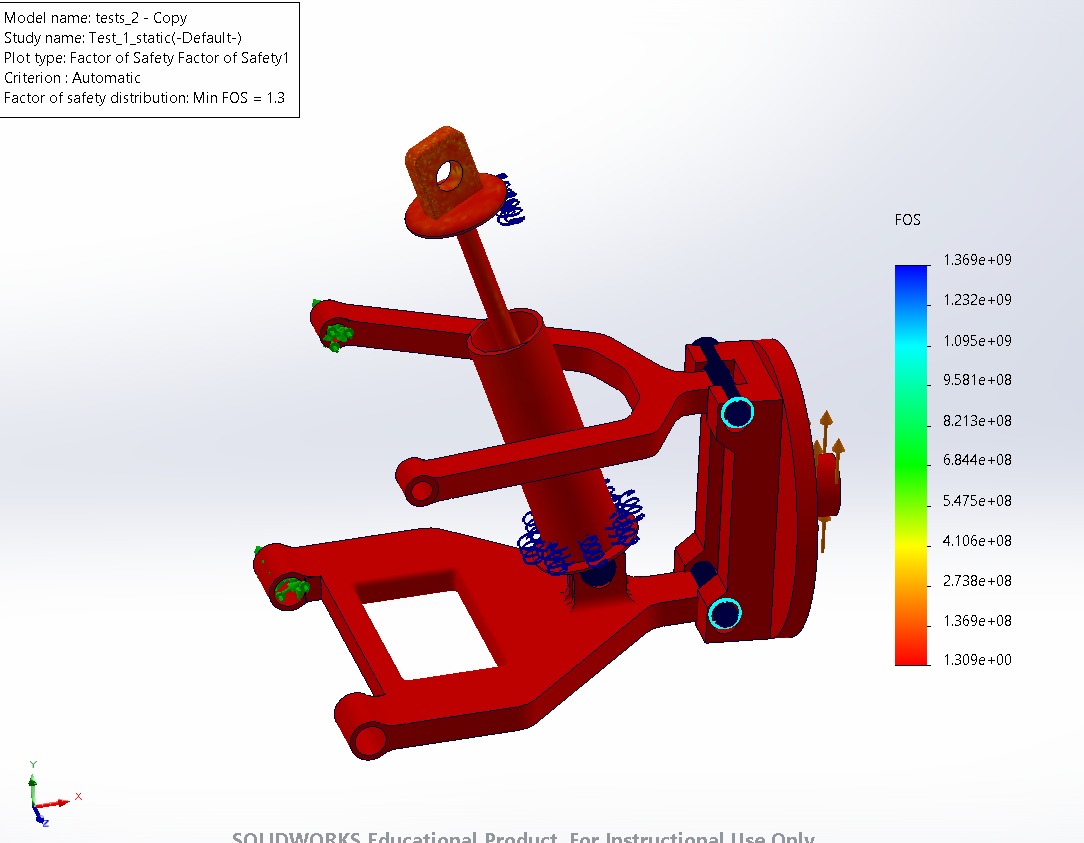
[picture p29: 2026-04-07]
images/IMG-20251128-WA0014.jpg

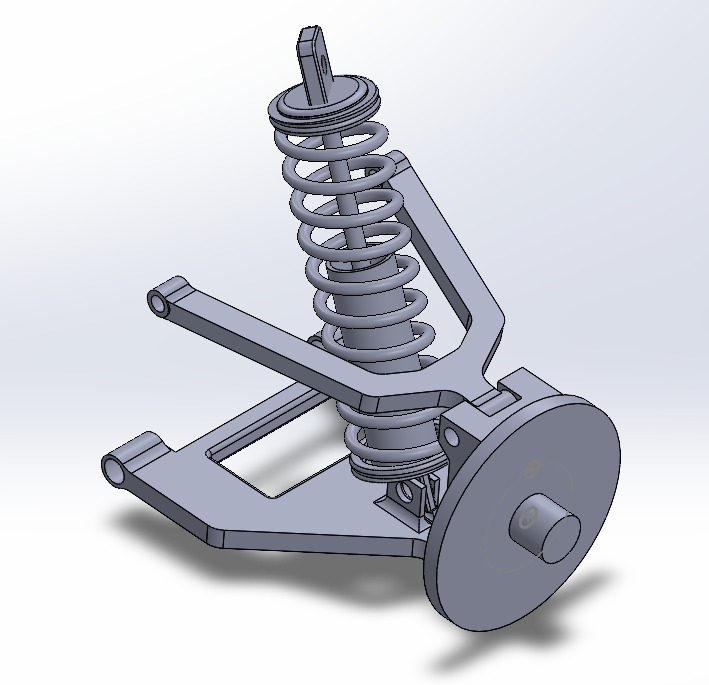
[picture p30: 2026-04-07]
images/IMG-20251128-WA0008.jpg

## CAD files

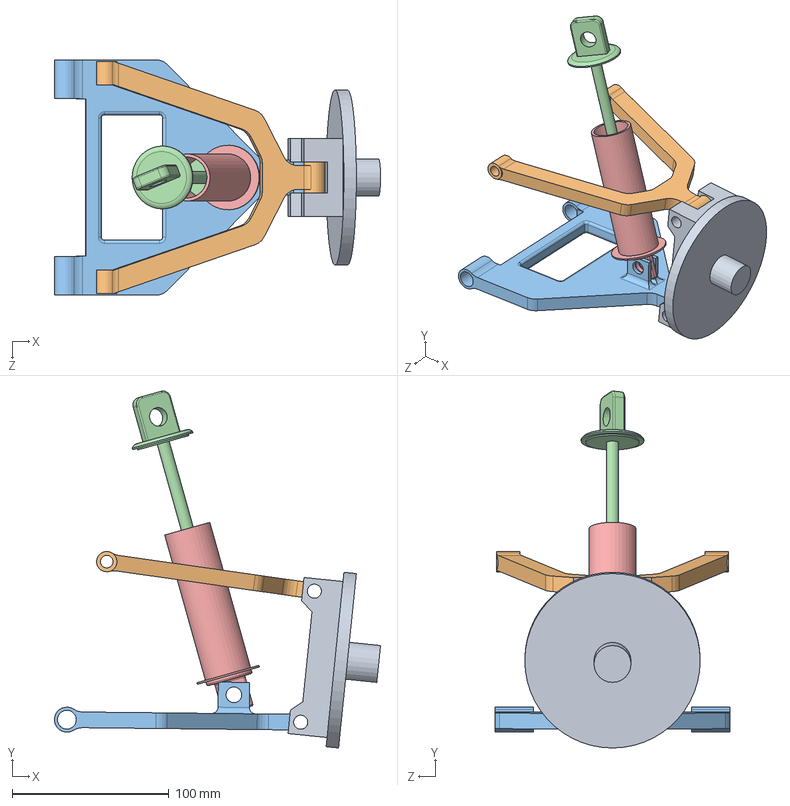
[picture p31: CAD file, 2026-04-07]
Parts/assembly.SLDASM
207.9 x 227.6 x 150.0 mm
damper_pipe
damper_rod
lower_2 - Copy
upper_2 - Copy
tyre hub - Copy

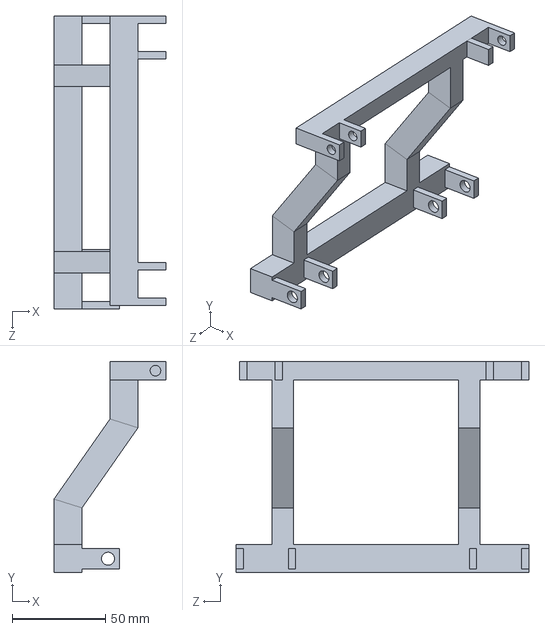
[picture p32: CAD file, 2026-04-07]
Parts/base_2.SLDPRT
60.0 x 113.2 x 157.0 mm

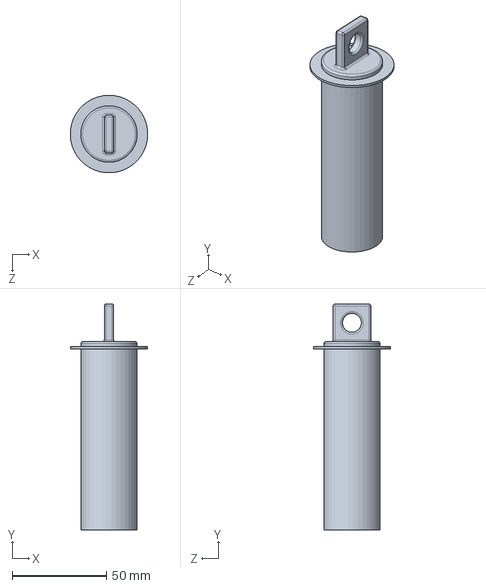
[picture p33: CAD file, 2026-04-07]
Parts/damper_pipe.SLDPRT
41.1 x 120.0 x 41.1 mm

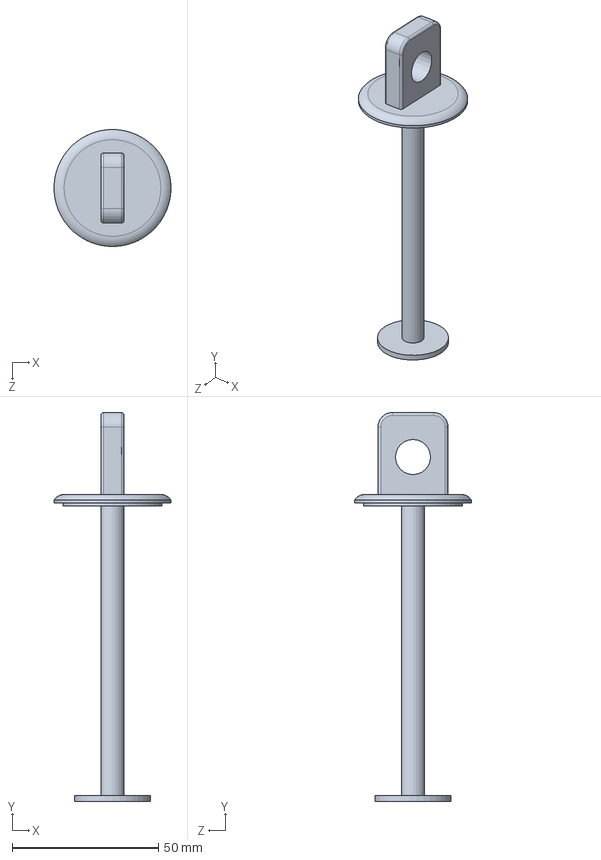
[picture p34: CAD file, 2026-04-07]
Parts/damper_rod.SLDPRT
40.0 x 133.0 x 40.0 mm

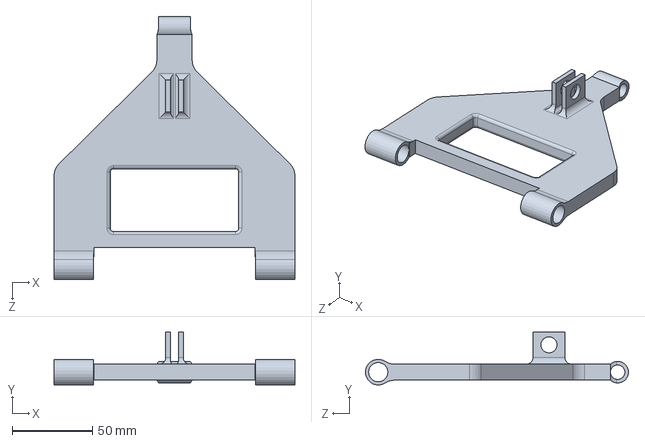
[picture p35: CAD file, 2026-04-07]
Parts/lower_2 - Copy.SLDPRT
150.0 x 33.0 x 163.7 mm

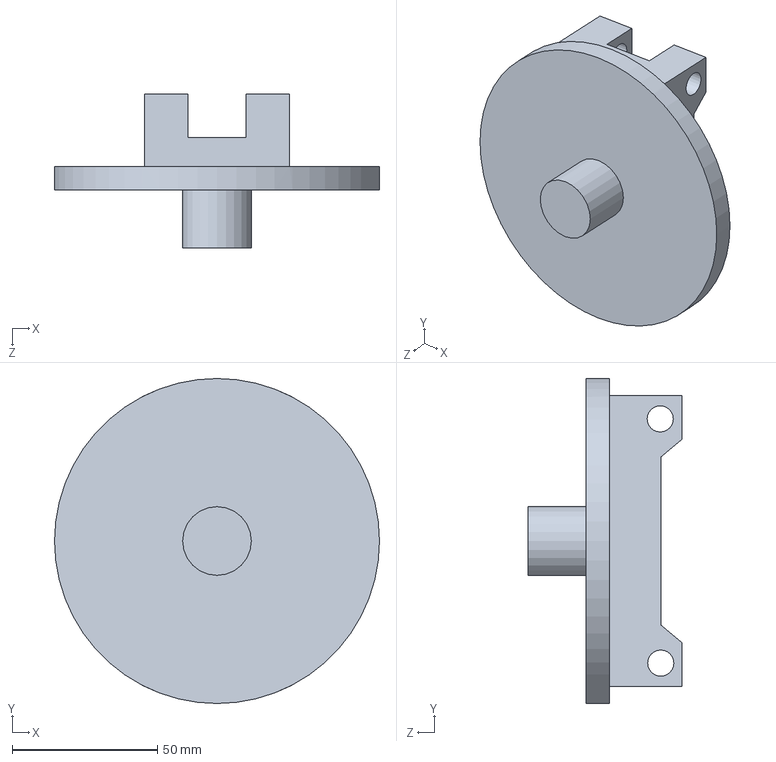
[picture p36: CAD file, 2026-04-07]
Parts/tyre hub - Copy.SLDPRT
111.8 x 111.8 x 53.0 mm

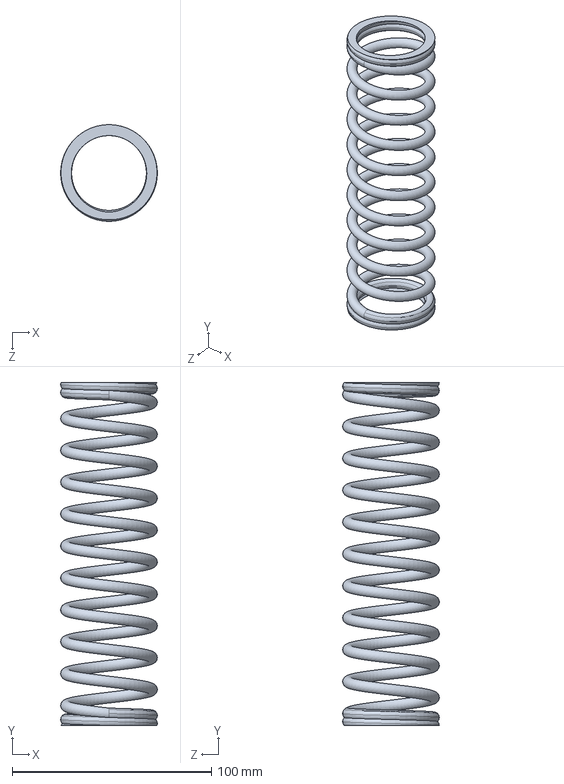
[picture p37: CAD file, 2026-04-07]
Parts/spring - Copy (2).SLDPRT
48.5 x 172.0 x 48.5 mm

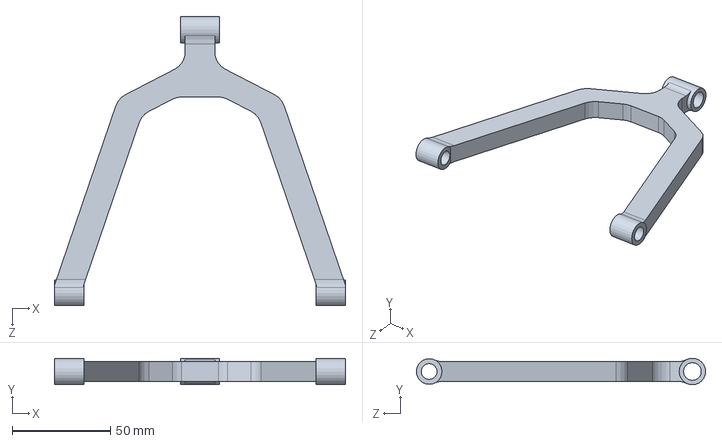
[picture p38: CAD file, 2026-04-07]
Parts/upper_2 - Copy.SLDPRT
147.8 x 13.5 x 146.9 mm
